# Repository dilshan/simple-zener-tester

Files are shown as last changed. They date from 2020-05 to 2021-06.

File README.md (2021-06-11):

# Experimental Zener Diode Tester

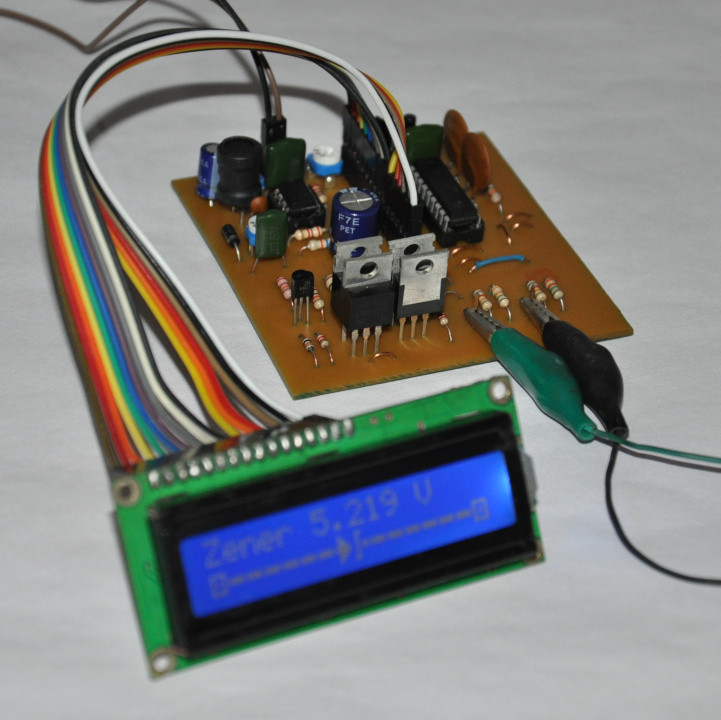
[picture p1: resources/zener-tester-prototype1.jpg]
Prototype version of Automatic Zener diode tester


Automatic Zener diode tester is capable of identifying Zener diodes up to 27.5V. Apart from that, it can be used to recognize leads of the diodes/Zeners and detect damaged diodes.

This tester is designed using well-known ICs such as MC34063 and PIC16F88.

This unit provides approximately 5% to 15% accurate readings. Based on our observations, the accuracy of this unit can increase by using resistors with 1% tolerance, stable booster circuit, accurate sampling method(s), and with a more optimized PCB layout.

### More prototypes

The following photographs illustrate the prototype version build by [Boris Peshev](https://github.com/BaiBorko).

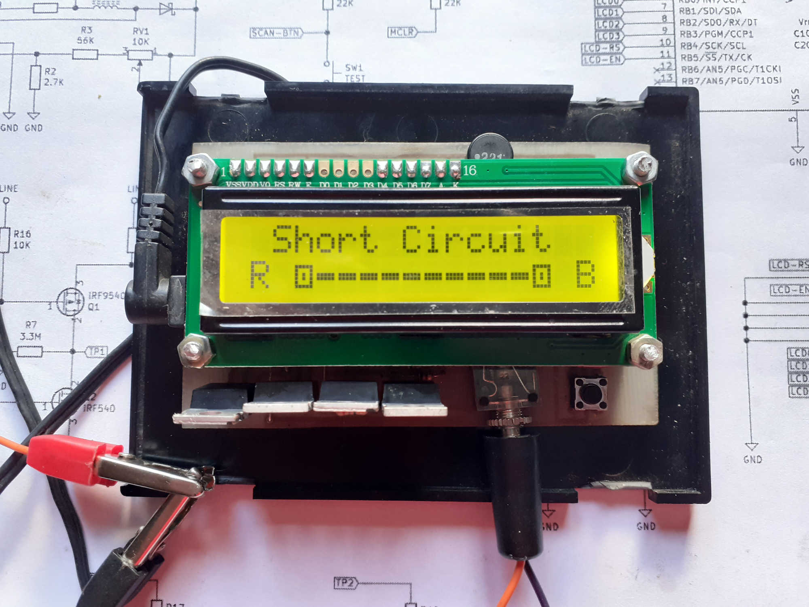
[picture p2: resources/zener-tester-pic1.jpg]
Short circuit detection

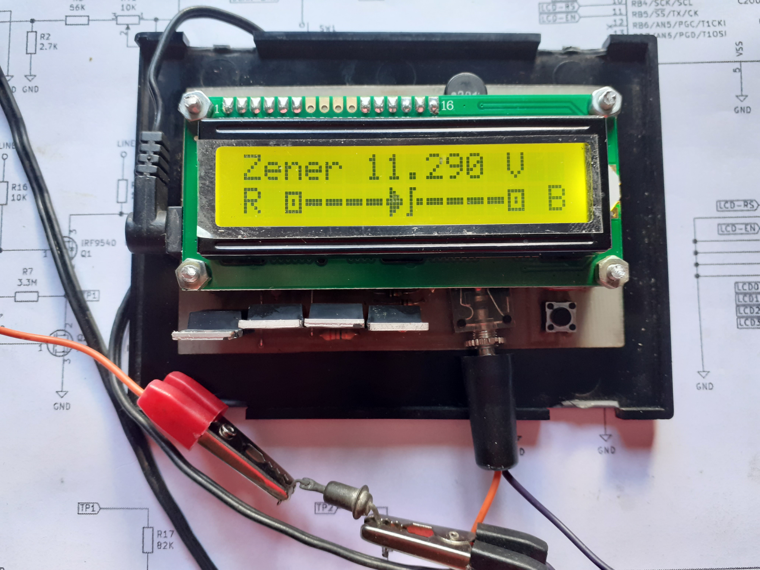
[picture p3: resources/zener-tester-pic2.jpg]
Reading got from vintage zener diode :O

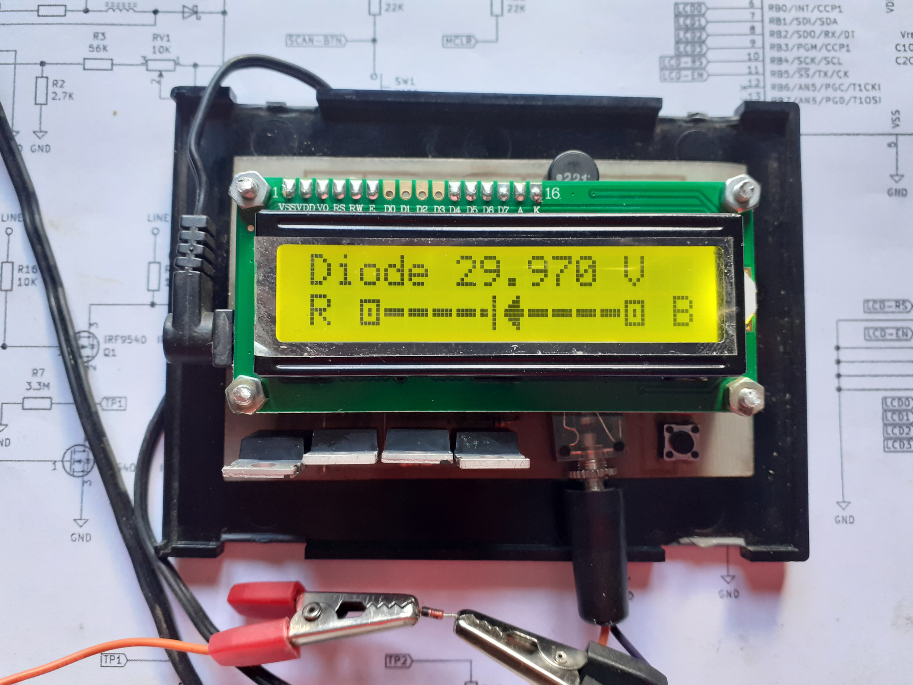
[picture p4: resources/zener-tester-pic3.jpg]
Reading from the generally available diode


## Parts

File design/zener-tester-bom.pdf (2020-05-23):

# Experimental Zener Diode Tester - Bill of Materials

Reference | Value | Description
U1 | MC34063AP | 1.5-A Boost/Buck/Inverting Switching Regulator
U2 | PIC16F88-IP | PIC16F Series, 7 kB Flash, 20 MHz 8-Bit Microcontroller
U3 | RC1602A | 16x2 character LCD module
Q1 | IRF9540 | P-channel 100V enhancement mode MOSFET
Q2 | IRF540 | N-channel 100V enhancement mode MOSFET
Q3 | IRF9540 | P-channel 100V enhancement mode MOSFET
Q4 | IRF540 | N-channel 100V enhancement mode MOSFET
Q6 | 2N4401 | General Purpose NPN Silicon Transistor
Q7 | 2N4401 | General Purpose NPN Silicon Transistor
R1 | 220Ω
R2 | 2.7KΩΩ
R3 | 56KΩΩ
R4 | 1Ω
R5 | 1Ω
R6 | 1KΩΩ | 1W Carbon Film Resistor
R7 | 3.3MΩ
R8 | 3.3MΩ
R9 | 22KΩΩ
R10 | 2.2KΩΩ
R11 | 10KΩΩ
R12 | 10KΩΩ
R13 | 2.2KΩΩ
R14 | 10KΩΩ
R15 | 22KΩΩ
R16 | 10KΩΩ
R17 | 82KΩΩ
R18 | 15KΩΩ
R19 | 82KΩΩ
R20 | 15KΩΩ
R21 | 22KΩΩ
R22 | 22KΩΩ
R23 | 470Ω
C1 | 0.001μF / 25VF / 25V | Ceramic Capacitor
C2 | 100μF / 25VF / 16V

C3 | 0.1μF / 25VF / 50V | Mylar Capacitor
C4 | 0.033μF / 25VF / 100V | Mylar Capacitor
C5 | 220μF / 25VF / 50V
C6 | 0.1μF / 25VF / 25V | Ceramic Capacitor
C7 | 0.1μF / 25VF / 25V | Ceramic Capacitor
C8 | 0.1μF / 25VF / 50V | Mylar Capacitor
C9 | 0.1μF / 25VF / 50V | Mylar Capacitor
RV1 | 10KΩΩ | Horizontal Preset Trimmer Potentiometer
RV2 | 20KΩΩ | Horizontal Preset Trimmer Potentiometer
L1 | 220uH | 1A Radial Inductor
D1 | 1N5819
SW1 | 6mm Tactile Switch

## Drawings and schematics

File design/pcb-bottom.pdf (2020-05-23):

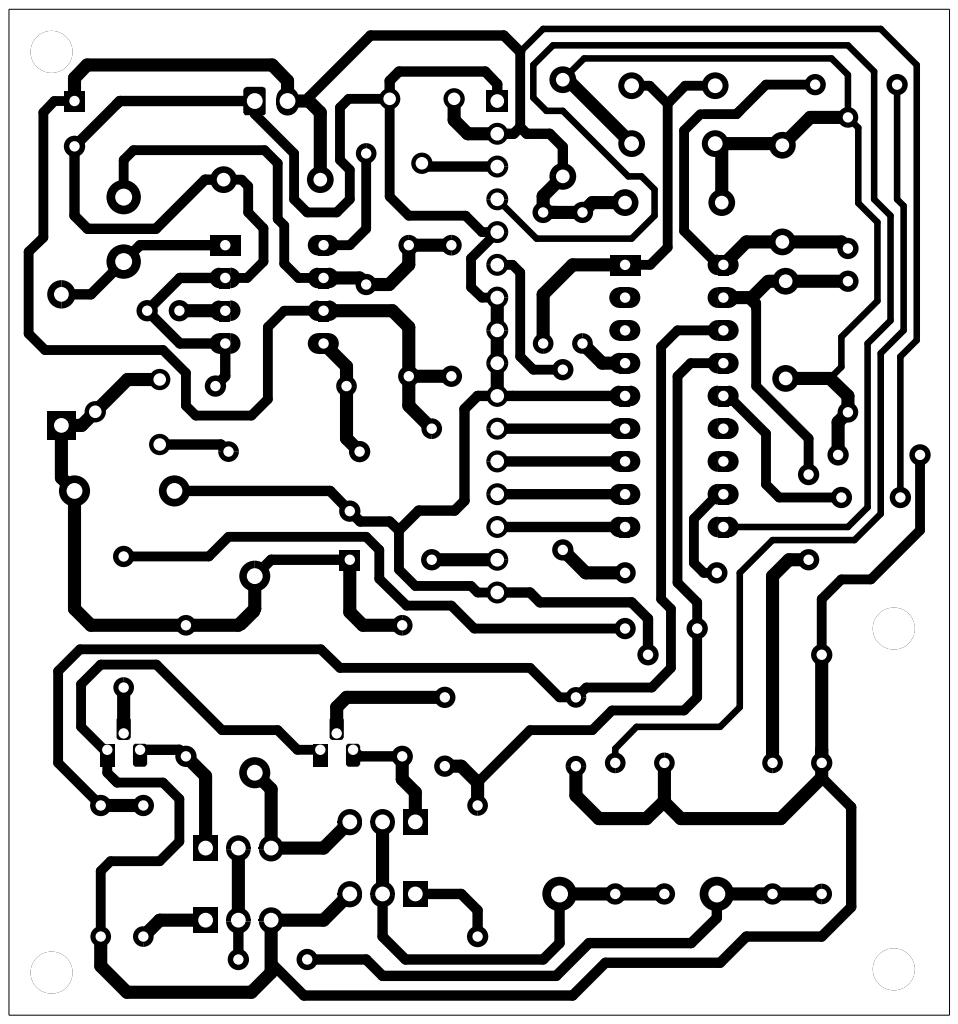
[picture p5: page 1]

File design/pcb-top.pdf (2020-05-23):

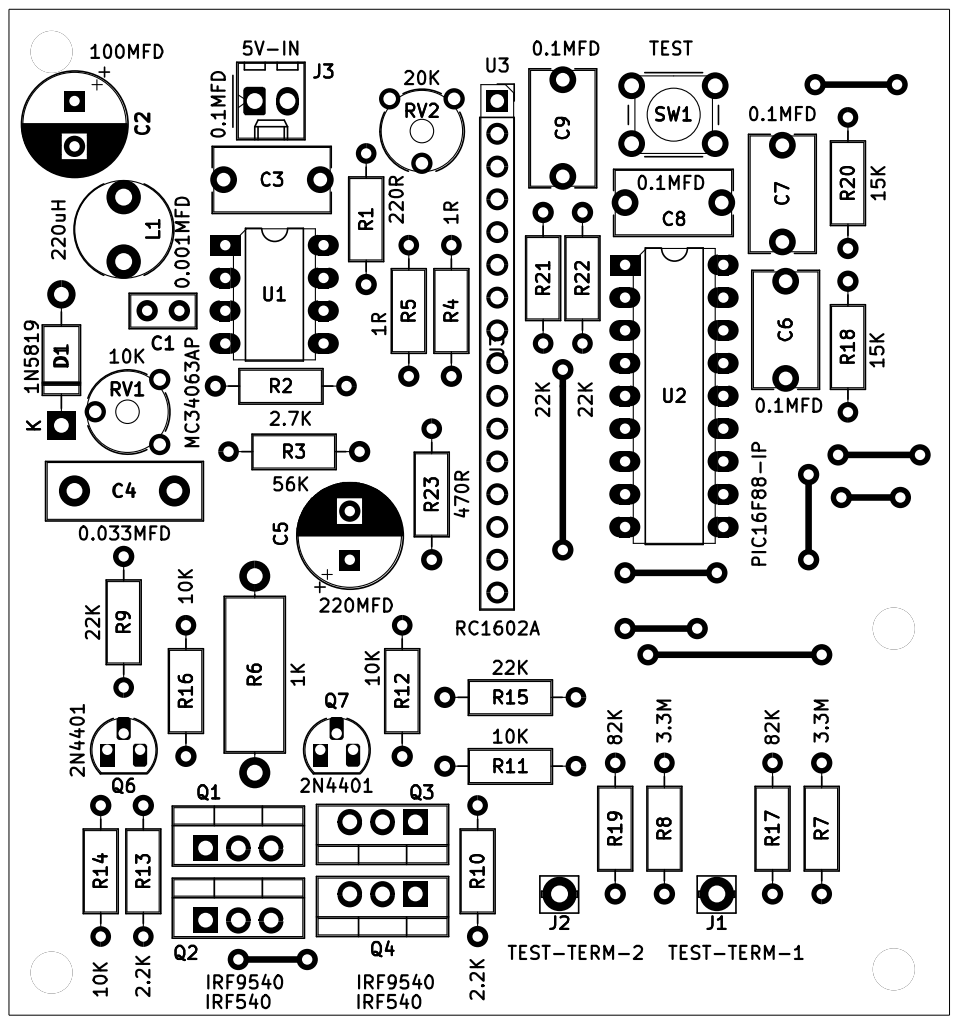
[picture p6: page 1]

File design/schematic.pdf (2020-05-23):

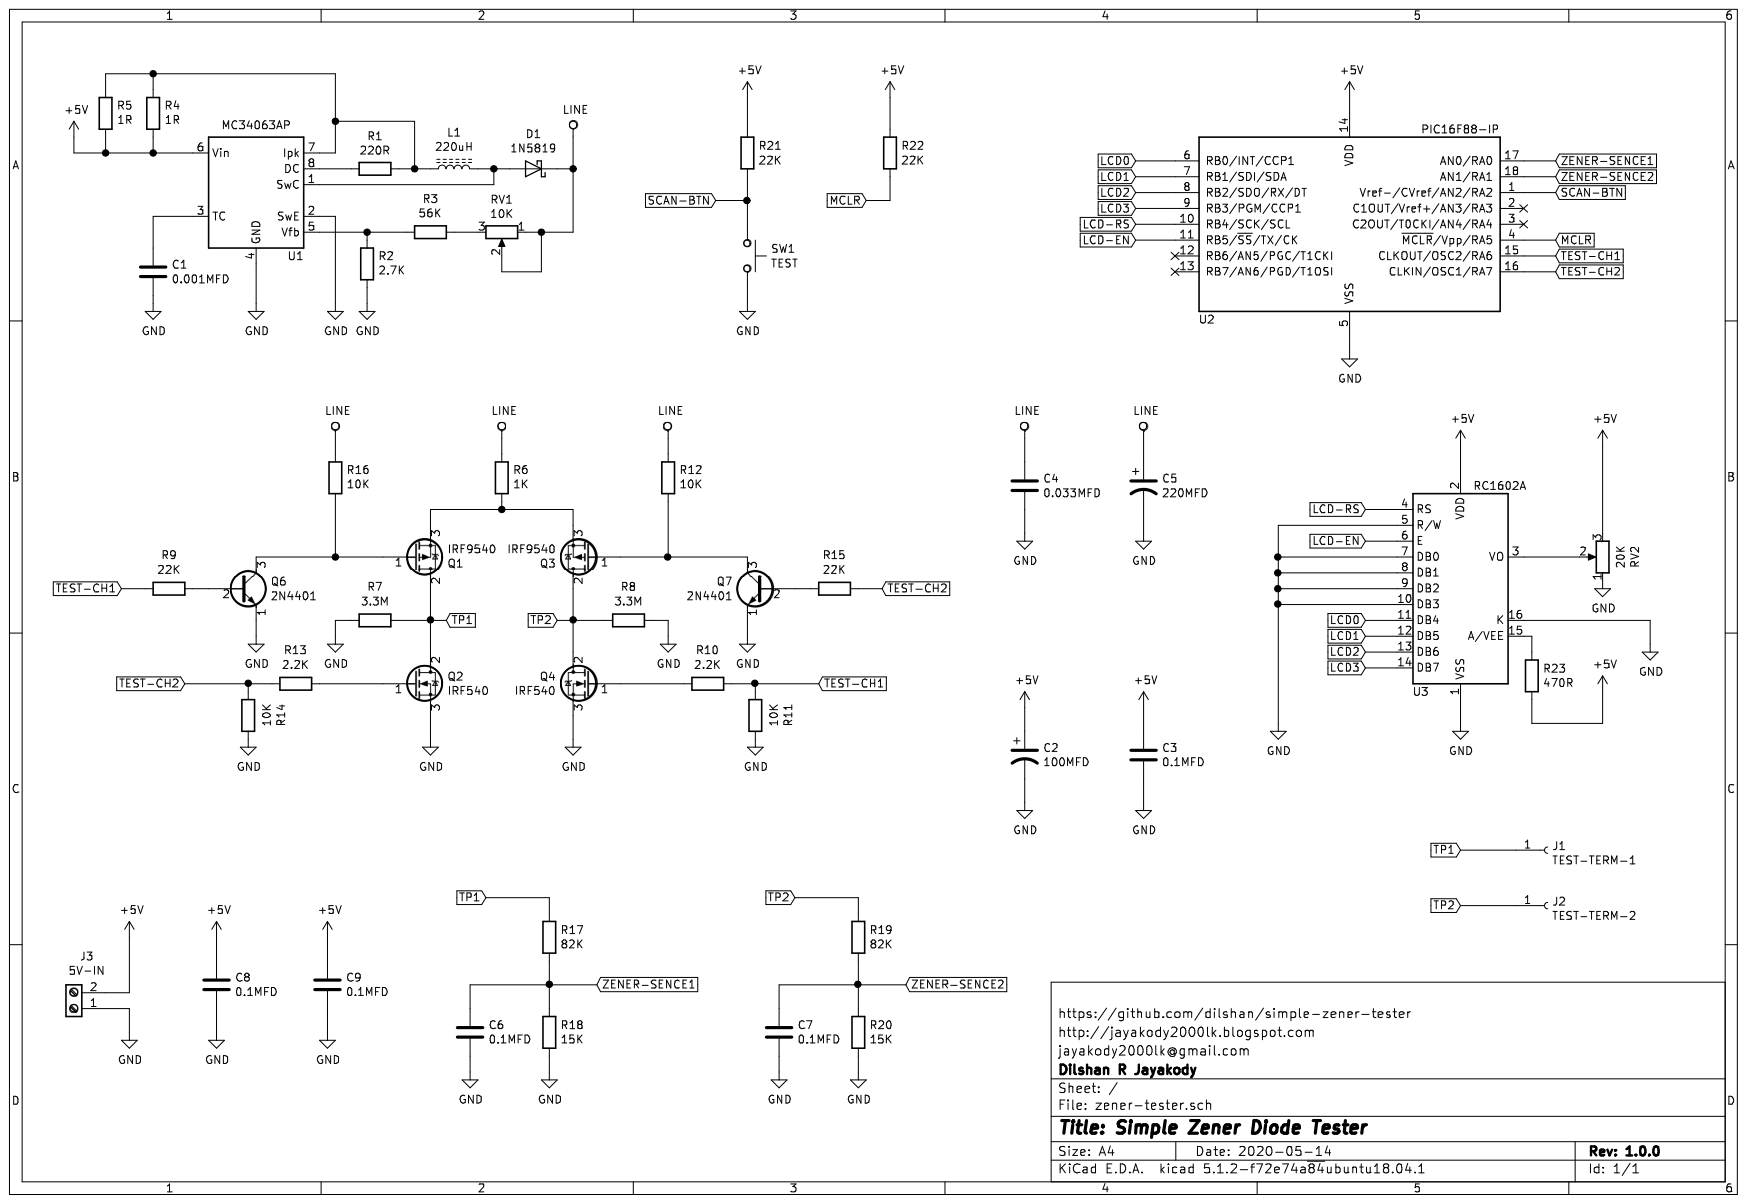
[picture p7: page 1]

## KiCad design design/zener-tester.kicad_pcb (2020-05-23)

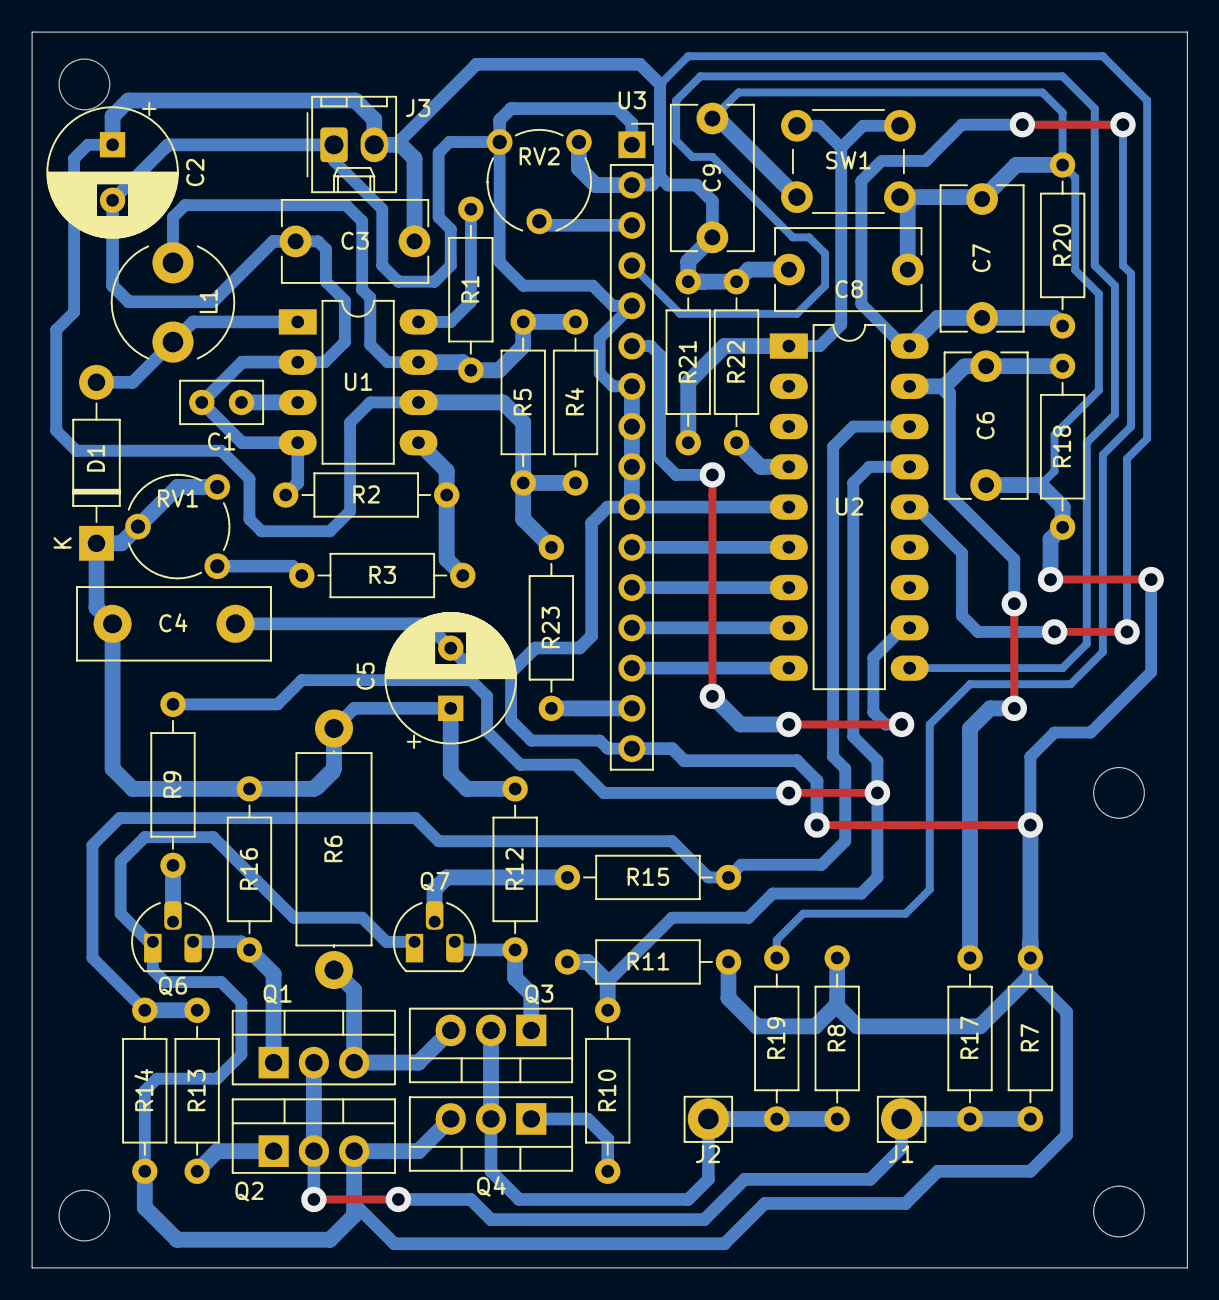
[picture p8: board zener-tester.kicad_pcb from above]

Board: 2 copper layers, 72.9 x 78.0 mm, 53 parts (0 on the bottom side), 32 nets.

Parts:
 : MountingHole_3.2mm_M3
 #2,  #3,  #4: MountingHole_3.2mm_M3
C1: 0.001MFD; C_Disc_D5.0mm_W2.5mm_P2.50mm
C2: 100MFD; CP_Radial_D8.0mm_P3.50mm
C3, C6, C7, C8, C9: 0.1MFD; C_Disc_D9.0mm_W5.0mm_P7.50mm
C4: 0.033MFD; C_Disc_D12.0mm_W4.4mm_P7.75mm
C5: 220MFD; CP_Radial_D8.0mm_P3.80mm
D1: 1N5819; D_DO-41_SOD81_P10.16mm_Horizontal
J1: TEST-TERM-1; Pin_D1.3mm_L11.3mm_W2.8mm_Flat
J2: TEST-TERM-2; Pin_D1.3mm_L11.3mm_W2.8mm_Flat
J3: 5V-IN; Molex_KK-254_AE-6410-02A_1x02_P2.54mm_Vertical
L1: 220uH; L_Radial_D7.5mm_P5.00mm_Fastron_07P
Q1, Q3: IRF9540; TO-220-3_Vertical
Q2, Q4: IRF540; TO-220-3_Vertical
Q6, Q7: 2N4401; TO-92L_HandSolder
R1: 220R; R_Axial_DIN0207_L6.3mm_D2.5mm_P10.16mm_Horizontal
R2: 2.7K; R_Axial_DIN0207_L6.3mm_D2.5mm_P10.16mm_Horizontal
R3: 56K; R_Axial_DIN0207_L6.3mm_D2.5mm_P10.16mm_Horizontal
R4, R5: 1R; R_Axial_DIN0207_L6.3mm_D2.5mm_P10.16mm_Horizontal
R6: 1K; R_Axial_DIN0414_L11.9mm_D4.5mm_P15.24mm_Horizontal
R7, R8: 3.3M; R_Axial_DIN0207_L6.3mm_D2.5mm_P10.16mm_Horizontal
R9, R15, R21, R22: 22K; R_Axial_DIN0207_L6.3mm_D2.5mm_P10.16mm_Horizontal
R10, R13: 2.2K; R_Axial_DIN0207_L6.3mm_D2.5mm_P10.16mm_Horizontal
R11, R12, R14, R16: 10K; R_Axial_DIN0207_L6.3mm_D2.5mm_P10.16mm_Horizontal
R17, R19: 82K; R_Axial_DIN0207_L6.3mm_D2.5mm_P10.16mm_Horizontal
R18, R20: 15K; R_Axial_DIN0207_L6.3mm_D2.5mm_P10.16mm_Horizontal
R23: 470R; R_Axial_DIN0207_L6.3mm_D2.5mm_P10.16mm_Horizontal
RV1: 10K; Potentiometer_Piher_PT-6-V_Vertical
RV2: 20K; Potentiometer_Piher_PT-6-V_Vertical
SW1: TEST; SW_PUSH_6mm
U1: MC34063AP; DIP-8_W7.62mm_LongPads
U2: PIC16F88-IP; DIP-18_W7.62mm_LongPads
U3: RC1602A; PinSocket_1x16_P2.54mm_Vertical

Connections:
+5V: C2.1, C3.1, C8.1, C9.1, J3.2, R4.1, R5.1, R21.1, R22.1, R23.2, RV2.3, U1.6, U2.14, U3.2
GND: C1.2, C2.2, C3.2, C4.2, C5.2, C6.2, C7.2, C8.2, C9.2, J3.1, Q2.3, Q4.3, Q6.1, Q7.1, R2.1, R7.1, R8.2, R11.2, R14.2, R18.2, R20.2, RV2.1, SW1.2, U1.2, U1.4, U2.5, U3.1, U3.5, U3.7, U3.8, U3.9, U3.10, U3.16
LCD0: U2.6, U3.11
LCD1: U2.7, U3.12
LCD2: U2.8, U3.13
LCD3: U2.9, U3.14
LCD-EN: U2.11, U3.6
LCD-RS: U2.10, U3.4
LINE: C4.1, C5.1, D1.1, R6.2, R12.2, R16.2, RV1.1, RV1.2
MCLR: R22.2, U2.4
unnamed: C1.1, U1.3
unnamed: D1.2, L1.2, U1.1
unnamed: L1.1, R1.1, R4.2, R5.2, U1.7
unnamed: Q1.1, Q6.3, R16.1
unnamed: Q1.3, Q3.3, R6.1
unnamed: Q2.1, R13.2
unnamed: Q3.1, Q7.3, R12.1
unnamed: Q4.1, R10.1
unnamed: Q6.2, R9.2
unnamed: Q7.2, R15.1
unnamed: R1.2, U1.8
unnamed: R2.2, R3.1, U1.5
unnamed: R3.2, RV1.3
unnamed: R23.1, U3.15
unnamed: RV2.2, U3.3
SCAN-BTN: R21.2, SW1.1, U2.1
TEST-CH1: R9.1, R10.2, R11.1, U2.15
TEST-CH2: R13.1, R14.1, R15.2, U2.16
TP1: J1.1, Q1.2, Q2.2, R7.2, R17.1
TP2: J2.1, Q3.2, Q4.2, R8.1, R19.1
ZENER-SENCE1: C6.1, R17.2, R18.1, U2.17
ZENER-SENCE2: C7.1, R19.2, R20.1, U2.18

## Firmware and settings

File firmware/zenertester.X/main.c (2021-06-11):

// **********************************************************************************
// MIT License
//
// Copyright (c) 2020 Dilshan R Jayakody
//
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
#include <stdio.h>

#include "main.h"
#include "lcd.h"

void main(void) 
{
    uint8_t lastButtonState;
    
    initSystem();
    __delay_ms(5);
    
    // Initialize LCD display.
    initLCD();
    clearLCD();
    
    // Allow time to stable the output of MC34063.
    printString("Initializing...", 15);
    __delay_ms(1500);
    
    // Load custom characters into LCD CGRAM.
    setGraphicRAM(LCD_CCHAR_POINT, customCharPoint);
    
    setGraphicRAM(LCD_CCHAR_ARROW_FWD, customCharFwdArrow);
    setGraphicRAM(LCD_CCHAR_ZENER_FWD, customCharFwdZener);
    setGraphicRAM(LCD_CCHAR_DIODE_FWD, customCharFwdDiode);
    
    setGraphicRAM(LCD_CCHAR_ARROW_REV, customCharRevArrow);
    setGraphicRAM(LCD_CCHAR_ZENER_REV, customCharRevZener);
    setGraphicRAM(LCD_CCHAR_DIODE_REV, customCharRevDiode);
    
    setGraphicRAM(LCD_CCHAR_WIRE, customCharWire);
           
    lastButtonState = PORTA;
    scanAndPrintZener();
    
    // Start service loop.
    while(1)
    {
        if(((PORTA & 0x04) == 0x04) && ((lastButtonState & 0x04) == 0x00))
        {
            scanAndPrintZener();
        }
        
        lastButtonState = PORTA; 
        __delay_ms(100);
    }
        
    return;
}

void initSystem()
{    
    // Set internal oscillator to 4 MHz.
    OSCCON = 0x64;
    
    // Disable unused peripherals.
    CCP1CON = 0x00;
    SSPCON  = 0x00;
    
    // Set PORTB as output port and reserved for LCD controller.
    PORTB = 0x00;
    TRISB = 0x00;
    
    // Set PORTA[0..1] for analog inputs. Remaining pins are configured as digital I/O.
    PORTA = 0x00;
    TRISA = 0x07;
    
    // Configure ADC to use internal references and set up other conversion settings.
    ANSEL = 0x03;
    ADCON0 = 0x01;
    ADCON1 = 0xC0;
}

uint16_t getADCValue(uint8_t channel)
{
    ADCON0bits.CHS = channel;  
    ADCON0bits.ADON = 1;
    
    // Wait until conversion completes.
    __delay_ms(2);
    ADCON0bits.GO_DONE = 1;
    while(ADCON0bits.GO_DONE == 1);
    
    return (ADRESH << 8) + ADRESL;
}

void getCurrentZenerValues(uint16_t *zenerTerminalVal)
{
    zenerTerminalVal[0] = getADCValue(0);
    __delay_us(50);
    zenerTerminalVal[1] = getADCValue(1);
    __delay_us(50);
    
    uint8_t scanPass = 0;
    
    while(scanPass < 50)
    {
        zenerTerminalVal[0] = (getADCValue(0) + zenerTerminalVal[0]) / 2;
        __delay_us(50);
        zenerTerminalVal[1] = (getADCValue(1) + zenerTerminalVal[1]) / 2;
        __delay_us(50);
        
        scanPass++;
    }
}

void scanForZener(uint16_t *readData)
{
    uint16_t tempVal[2];
    
    readData[0] = 0;
    readData[1] = 0;
    
    // Scan input terminals in normal direction and get ADC values.
    PORTA = 0x40;
    __delay_ms(120);            
    getCurrentZenerValues(tempVal);
    PORTA = 0x00;
    
    if(tempVal[1] < tempVal[0])
    {
        readData[0] = tempVal[0] - tempVal[1];
    }
    else
    {
        readData[0] = tempVal[1] - tempVal[0];
    }
    
    // Scan input terminals in reverse direction and get ADC values.
    PORTA = 0x80;
    __delay_ms(120);
    getCurrentZenerValues(tempVal);
    PORTA = 0x00;
    
    if(tempVal[1] < tempVal[0])
    {        
        readData[1] = tempVal[0] - tempVal[1];
    }
    else
    {
        readData[1] = tempVal[1] - tempVal[0];
    }
}

uint32_t adcToVolts(uint16_t adcVal)
{
    uint32_t adcVolt = (30000000 / 1023)  * adcVal;
    return adcVolt;
}

void printFloat(uint32_t *val)
{
    char lineBuffer[18];
    
    // Split exponent and fraction part from the returned value.
    int16_t exp = *val / 1000000;
    int16_t frac = ((int32_t)(*val - (exp * 1000000))) / 1000;
    
    // Format output and print on current location of LCD.
    sprintf(lineBuffer, "%d.%d V", exp, frac);
    printString(lineBuffer, 18);
}

void scanAndPrintZener()
{
    uint16_t scanVal[2] = {0, 0};
    uint16_t maxVal;
    uint32_t voltFwd, voltRev;
    uint32_t maxVoltage;
    uint8_t temp, direction;
    
    // Clean LCD.
    clearLCD();
    returnHome();
    
    // Scan terminals and get voltage readings in forward and reverse directions.
    scanForZener(scanVal);
    voltFwd = adcToVolts(scanVal[0]);
    voltRev = adcToVolts(scanVal[1]);
    
    // Convert voltages to 100mV scale for comparison.
    scanVal[0] = voltFwd / 100000;
    scanVal[1] = voltRev / 100000;
              
    // Check for open terminals.
    if((scanVal[0] >= OPEN_VOLTAGE) && (scanVal[1] >= OPEN_VOLTAGE))
    {
        printString(" Connect Zener", 14);        
        return;
    }
    
    // Check for short-circuit.
    if((scanVal[0] <= SHORT_CIRCUIT_VOLTAGE) && (scanVal[1] <= SHORT_CIRCUIT_VOLTAGE))
    {
        printString(" Short Circuit", 14);
        
        setLocation(0, 2);
        printString("R ",2);
        sendChr(LCD_CCHAR_POINT);
        
        for(temp = 0; temp < 10; temp++)
        {
            sendChr(LCD_CCHAR_WIRE);
        }
        sendChr(LCD_CCHAR_POINT);
        printString(" B",2);
        return;
    }
    
    // Identify direction of the diode / zener.
    if(voltFwd > voltRev)
    {
        maxVal = scanVal[0];
        maxVoltage = voltFwd;
        direction = DIRECTION_FWD;        
    }
    else
    {
        maxVal = scanVal[1];
        maxVoltage = voltRev;
        direction = DIRECTION_REV;
    }
    
    // Maximum value is too close to upper voltage limit.
    if(maxVal >= OPEN_VOLTAGE)
    {
        // Detect as diode and show details.
        printString("Diode ", 6);
        printFloat(&maxVoltage);
        
        // Draw diode direction.
        setLocation(0, 2);
        printString("R ",2);
        sendChr(LCD_CCHAR_POINT);
                
        for(temp = 0; temp < 4; temp++)
        {
            sendChr(LCD_CCHAR_WIRE);
        }
        
        if(direction == DIRECTION_FWD)
        {
            // Diode is connected in forward direction.
            sendChr(LCD_CCHAR_ARROW_FWD);
            sendChr(LCD_CCHAR_DIODE_FWD);
        }
        else
        {
            // Diode is connected in reverse direction.
            sendChr(LCD_CCHAR_DIODE_REV);
            sendChr(LCD_CCHAR_ARROW_REV);
        }
        
        for(temp = 0; temp < 4; temp++)
        {
            sendChr(LCD_CCHAR_WIRE);
        }
        
        sendChr(LCD_CCHAR_POINT);
        printString(" B",2);
        return;
    }
    
    // Detect zener diode and show information.
    printString("Zener ", 6);
    printFloat(&maxVoltage);
    
    // Draw diode direction.
    setLocation(0, 2);
    printString("R ",2);
    sendChr(LCD_CCHAR_POINT);
        
    for(temp = 0; temp < 4; temp++)
    {
        sendChr(LCD_CCHAR_WIRE);
    }

    if(direction == DIRECTION_FWD)
    {
        // Diode is connected in forward direction.
        sendChr(LCD_CCHAR_ARROW_FWD);
        sendChr(LCD_CCHAR_ZENER_FWD);
    }
    else
    {
        // Diode is connected in reverse direction.
        sendChr(LCD_CCHAR_ZENER_REV);
        sendChr(LCD_CCHAR_ARROW_REV);
    }

    for(temp = 0; temp < 4; temp++)
    {
        sendChr(LCD_CCHAR_WIRE);
    }
    
    sendChr(LCD_CCHAR_POINT); 
    printString(" B",2);
}

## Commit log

2020-05-23 Initial commit.
    [zener-tester.kicad_pcb, zener-tester.sch]
2020-05-23 Update readme with prototype image.
2021-06-10 Add feature to print on LCD the color of crocodile clips. R for red and B - for black in my case . Add pcb in sprint- layout format.
2021-06-11 Initial prototype of the Zener diode tester
